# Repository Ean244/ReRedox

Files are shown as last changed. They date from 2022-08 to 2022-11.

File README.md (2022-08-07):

## Terminal v1

Terminal is a ergonomic split keyboard design modified from the [Redox Project](https://github.com/mattdibi/redox-keyboard) by [Mattia Dal Ben (aka u/TiaMaT102)](mailto:matthewdibi@gmail.com).

Key modifications include:

* Replacement of 1.25U keycaps with 1.5U keycaps (which are easier to find / typically found in keycap sets)
* Adding two OLED panels with WPM counter and custom pixel art
* Changing shape of through-holes for the switches the from irregular shapes to regular ones
  * Some board manufacturers do not accept irregular shapes (for me it was JLCPB)
* Adding support stands for a 6 degree tilt

A [sandwich transparent acrylic casing](https://github.com/Ean244/Terminal-Acrylic-Casing) was designed for Terminal v1.

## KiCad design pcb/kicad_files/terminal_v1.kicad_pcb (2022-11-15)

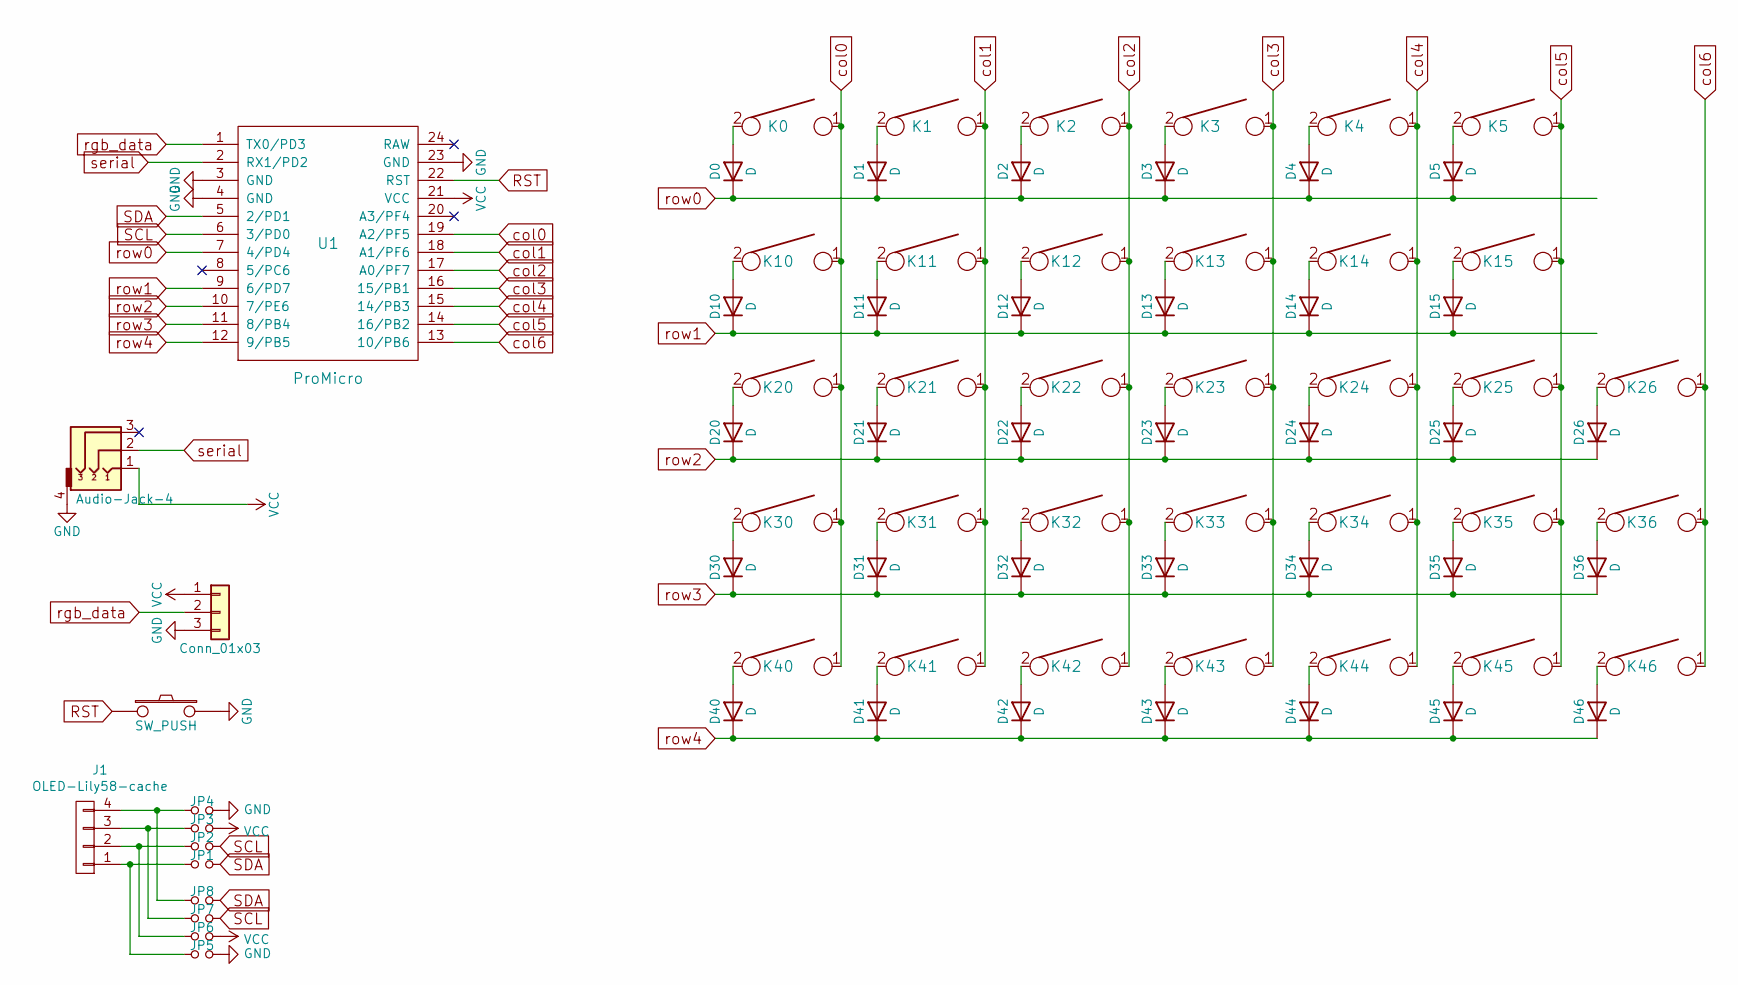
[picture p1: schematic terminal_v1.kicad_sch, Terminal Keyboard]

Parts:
D0, D1, D2, D3, D4, D5, D10, D11, D12, D13, D14, D15, D20, D21, D22, D23, D24, D25, D26, D30, D31, D32, D33, D34, D35, D36, D40, D41, D42, D43, D44, D45, D46: D; Diode-dual
J1: OLED-Lily58-cache; OLED_4Pin
JP1, JP2, JP3, JP4, JP5, JP6, JP7, JP8: Jumper_NO_Small; Jumper
K0, K1, K2, K3, K4, K5, K10, K11, K12, K13, K14, K15, K20, K21, K22, K23, K24, K25, K26, K30, K31, K32, K33, K34, K35, K36, K40, K41, K42, K43, K44, K45, K46: KEYSW; SW_MX_reversible
U1: ProMicro; ArduinoProMicro

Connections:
GND: JP4.2, JP5.2, U1.3 (GND), U1.4 (GND), U1.23 (GND); also elsewhere on the board
unnamed: D0.2 (A), K0.2
unnamed: D1.2 (A), K1.2
unnamed: D2.2 (A), K2.2
unnamed: D3.2 (A), K3.2
unnamed: D4.2 (A), K4.2
unnamed: D5.2 (A), K5.2
unnamed: D10.2 (A), K10.2
unnamed: D11.2 (A), K11.2
unnamed: D12.2 (A), K12.2
unnamed: D13.2 (A), K13.2
unnamed: D14.2 (A), K14.2
unnamed: D15.2 (A), K15.2
unnamed: D20.2 (A), K20.2
unnamed: D21.2 (A), K21.2
unnamed: D22.2 (A), K22.2
unnamed: D23.2 (A), K23.2
unnamed: D24.2 (A), K24.2
unnamed: D25.2 (A), K25.2
unnamed: D26.2 (A), K26.2
unnamed: D30.2 (A), K30.2
unnamed: D31.2 (A), K31.2
unnamed: D32.2 (A), K32.2
unnamed: D33.2 (A), K33.2
unnamed: D34.2 (A), K34.2
unnamed: D35.2 (A), K35.2
unnamed: D36.2 (A), K36.2
unnamed: D40.2 (A), K40.2
unnamed: D41.2 (A), K41.2
unnamed: D42.2 (A), K42.2
unnamed: D43.2 (A), K43.2
unnamed: D44.2 (A), K44.2
unnamed: D45.2 (A), K45.2
unnamed: D46.2 (A), K46.2
unnamed: J1.1, JP1.1, JP5.1
unnamed: J1.2, JP2.1, JP6.1
unnamed: J1.3, JP3.1, JP7.1
unnamed: J1.4, JP4.1, JP8.1
RST: U1.22 (RST); also elsewhere on the board
SCL: JP2.2, JP7.2, U1.6 (3/PD0)
SDA: JP1.2, JP8.2, U1.5 (2/PD1)
VCC: JP3.2, JP6.2, U1.21 (VCC); also elsewhere on the board
col0: K0.1, K10.1, K20.1, K30.1, K40.1, U1.19 (A2/PF5)
col1: K1.1, K11.1, K21.1, K31.1, K41.1, U1.18 (A1/PF6)
col2: K2.1, K12.1, K22.1, K32.1, K42.1, U1.17 (A0/PF7)
col3: K3.1, K13.1, K23.1, K33.1, K43.1, U1.16 (15/PB1)
col4: K4.1, K14.1, K24.1, K34.1, K44.1, U1.15 (14/PB3)
col5: K5.1, K15.1, K25.1, K35.1, K45.1, U1.14 (16/PB2)
col6: K26.1, K36.1, K46.1, U1.13 (10/PB6)
rgb_data: U1.1 (TX0/PD3); also elsewhere on the board
row0: D0.1 (K), D1.1 (K), D2.1 (K), D3.1 (K), D4.1 (K), D5.1 (K), U1.7 (4/PD4)
row1: D10.1 (K), D11.1 (K), D12.1 (K), D13.1 (K), D14.1 (K), D15.1 (K), U1.9 (6/PD7)
row2: D20.1 (K), D21.1 (K), D22.1 (K), D23.1 (K), D24.1 (K), D25.1 (K), D26.1 (K), U1.10 (7/PE6)
row3: D30.1 (K), D31.1 (K), D32.1 (K), D33.1 (K), D34.1 (K), D35.1 (K), D36.1 (K), U1.11 (8/PB4)
row4: D40.1 (K), D41.1 (K), D42.1 (K), D43.1 (K), D44.1 (K), D45.1 (K), D46.1 (K), U1.12 (9/PB5)
serial: U1.2 (RX1/PD2); also elsewhere on the board

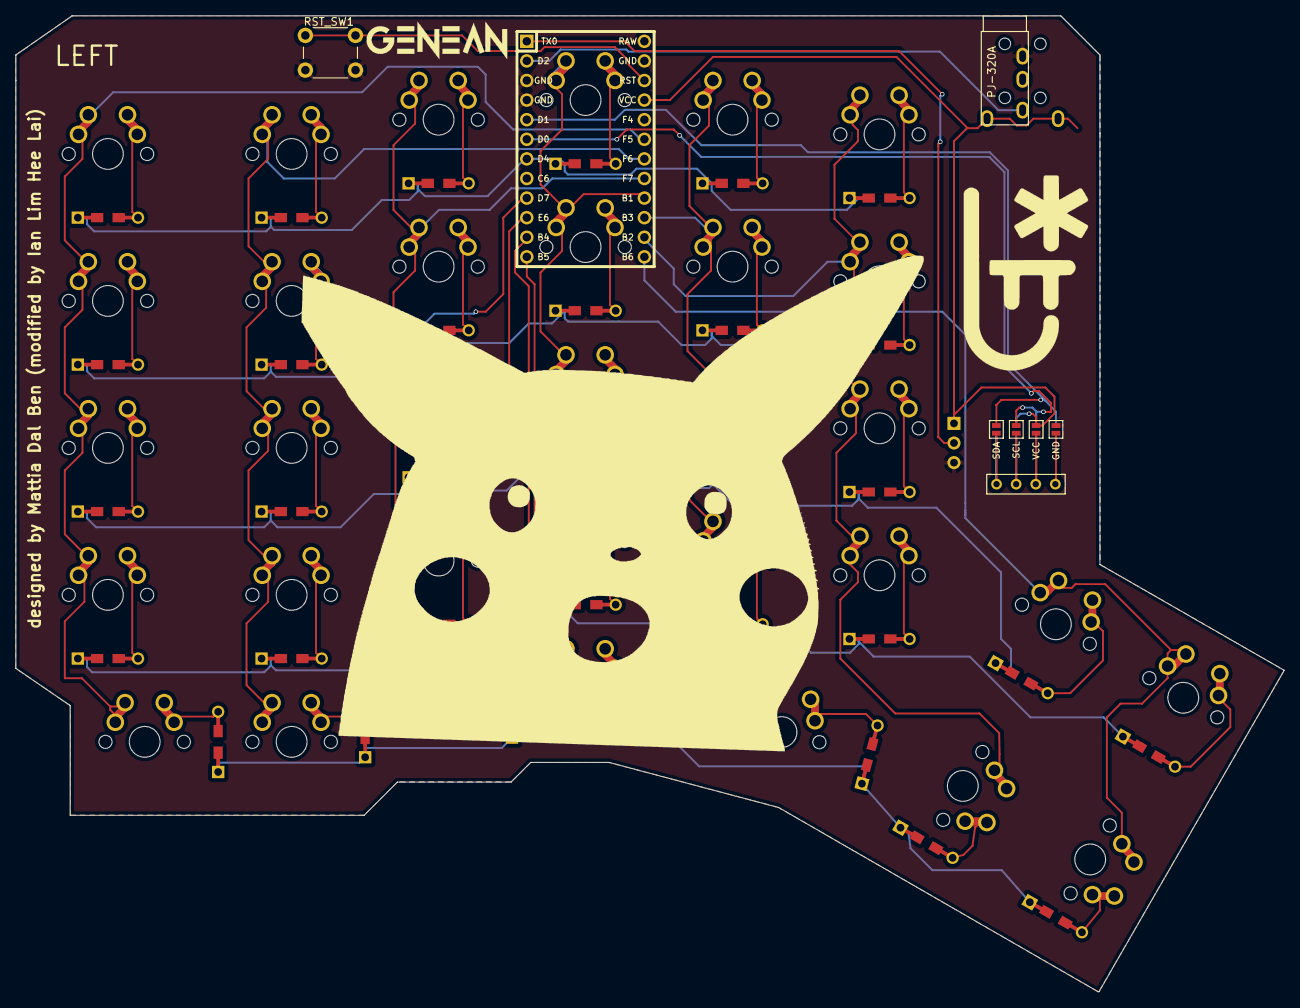
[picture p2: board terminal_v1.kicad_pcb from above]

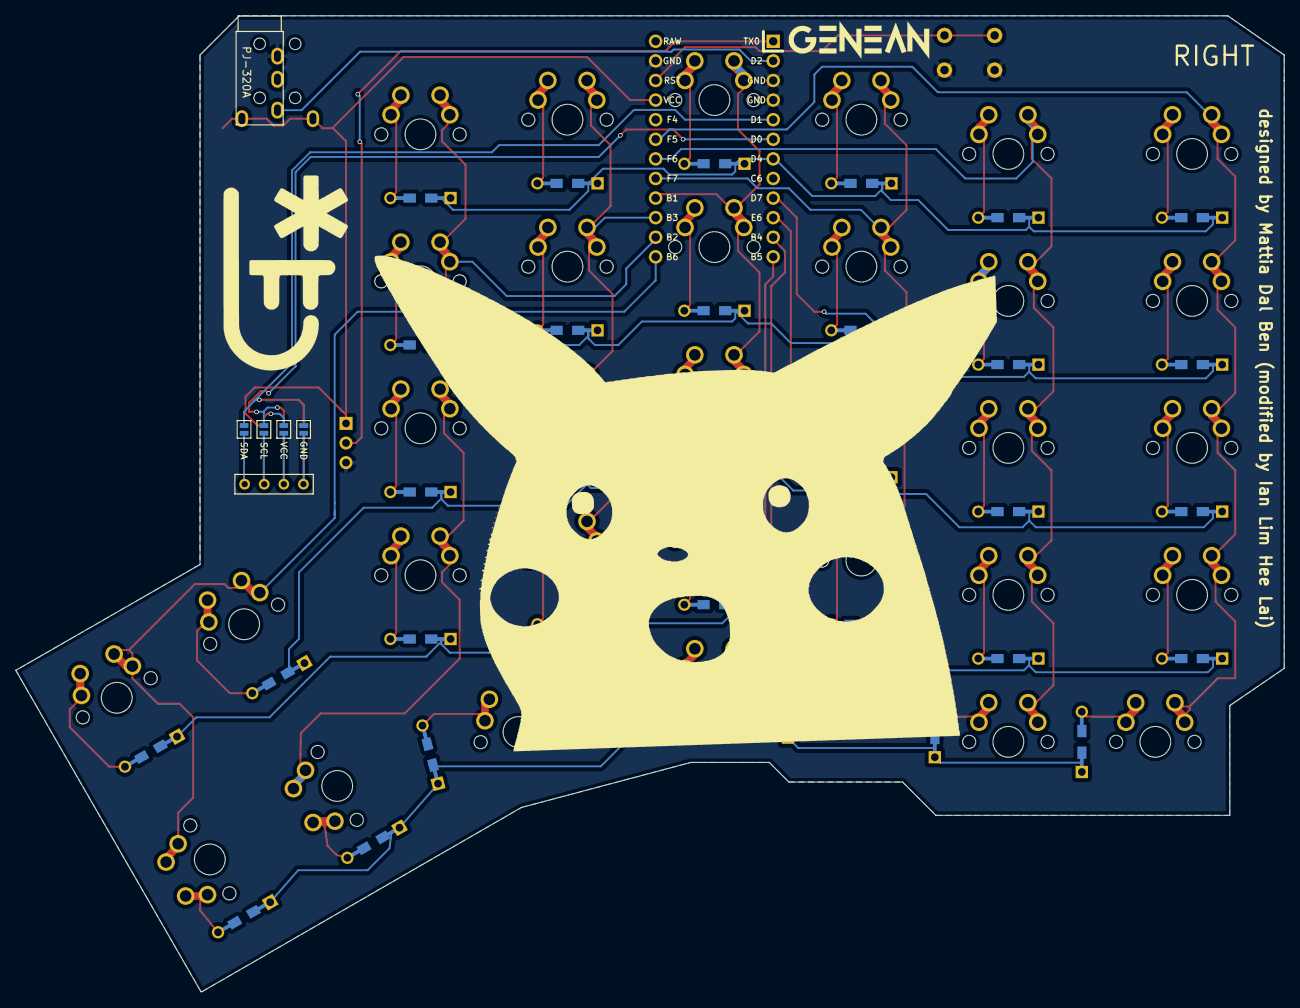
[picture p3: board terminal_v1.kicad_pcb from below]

Board: 2 copper layers, 164.4 x 126.5 mm, 79 parts (4 on the bottom side), 56 nets.

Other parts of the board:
RGB_STRIP1: Conn_01x03; Pin_Header_Straight_1x03_Pitch2.54mm
RST_SW1: SW_PUSH; SW_PUSH_6mm_h4.3mm
TRRS1: Audio-Jack-4; TRRS-PJ-320A-dual

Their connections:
GND: RGB_STRIP1.3, RST_SW1.2, TRRS1.4; also elsewhere on the board
RST: RST_SW1.1; also elsewhere on the board
VCC: RGB_STRIP1.1, TRRS1.1; also elsewhere on the board
rgb_data: RGB_STRIP1.2; also elsewhere on the board
serial: TRRS1.2; also elsewhere on the board

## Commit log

2022-08-07 included oled updates
    [redox_rev1-B_Cu.gbl, redox_rev1-B_Mask.gbs, redox_rev1-B_Paste.gbp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]
2022-11-15 Added gitignore
    [redox_rev1-2020-05-13-14-47-40.sch, redox_rev1.kicad_pcb, redox_rev1.kicad_sch]
2022-11-15 removed legacy files
    [redox_rev1.sch, terminal_v1.kicad_pcb, terminal_v1.kicad_sch]

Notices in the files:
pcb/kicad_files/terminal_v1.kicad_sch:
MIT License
